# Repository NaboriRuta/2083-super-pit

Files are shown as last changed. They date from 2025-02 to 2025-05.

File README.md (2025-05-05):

# 2083-super-pit
#### Design by Shelton Adams
#### To download these files, download git and run one of these commands in your computer's terminal:

1. For SOLIDWORKS Files: ```git clone https://github.com/NaboriRuta/2083-super-pit/tree/swx```
2. For STEP Files: ```git clone https://github.com/NaboriRuta/2083-super-pit/tree/step```

## Some important things to note:
- Parts modeled can all be found at [The DIY Road Cases Store](https://diyroadcasesstore.com)
  - Some dimensions weren't included, but everything is as accurate as possible
  - I'd suggest looking at [Penn-Elcom](https://penn-elcom.com) for more parts because they have more parts and the DIY Road Cases Store gets basically everything from them
- The plywood our team used is 15/32" thick
- Dimensions are rounded down to the nearest 1/16"
- When it comes to placements of tongue and groove extrusions: All tongue extrusions are on the main bottom compartment and groove extrusions are everywhere else

## Quick File Description
- plywood-cut-lists contains a cut list of how the pieces are cut out initially as well as what the finished pieces will end up looking like
- swx-files contains all of the SOLIDWORKS CAD files used
- step-files contains the main sections of the SOLIDWORKS files, just in .STEP format so it's compatible with all CAD software
- model-pics contains pictures of the Super Pit for people who don't have SOLIDWORKS or any form of CAD on their computer

## For CAD People
- You will notice parts like "Tongue Extrusion Alt 1"
  - These are so the assemblies don't make a bunch of errors when rebuilding
- Some designs were too detail-intensive to do from scratch, so you'll see lots of boxes with the same overall dimensions and the name carved out
- Due to all dimensions being rounded down to the nearest 1/16", there are gaps between:
  - Edges where aluminum extrusions meet
  - the pit pieces themselves when the full assembly is in its closed state
- Each piece does need to be changed individually. Adding global variables to dimensions unfortunately breaks everything
- If you're changing the design to be less than 4' tall/wide, the back wall of the front half no longer needs to be two separate pieces
- Cut Lists can be changed to fit pieces differently, if you're changing the CAD at all
- step-files doesn't contain all of the files used due to the nature of how step files work
  - Separate documents can be made for the individual parts outside of the assembly

#### If you have any questions, feel free to respond to the [Delphi Post](./) (Not Out Yet) or message me via Discord (@naboriruta)

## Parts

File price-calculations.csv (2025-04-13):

Item | Units Needed | Price Per Unit | Total | Additional Comments | Lengths Used (in) | Lengths Per Unit (in) | Lengths Bought (in)
Double Laminated Plywood | 5 | $127.00 | $635.00 | Refer to Cut Lists Here
Single Angle Extrusion | 8 | $12.80 | $102.40 | Dimensions to the right are measured using SWX | 596.5 | 79 | 632
Tongue Extrusion | 2 | $22.70 | $45.40 | Dimensions to the right are measured using SWX | 257.75 | 144 | 288
Groove Extrusion | 3 | $24.00 | $72.00 | Dimensions to the right are measured using SWX | 381.625 | 144 | 432
U-Shape Extrusion | 3 | $12.40 | $37.20 | Dimensions to the right are measured using SWX | 205.75 | 78 | 234
Panel Joiner | 1 | $48.20 | $48.20 | Dimensions to the right are measured using SWX | 71 | 79 | 79
Latches - Recessed | 14 | $11.85 | $165.90
Latches - Surface | 2 | $6.50 | $13.00
Handles | 16 | $6.40 | $102.40 | Refer to Super Pit Pics for placement instruction
Corners | 8 | $2.10 | $16.80 | Refer to Super Pit Pics for placement instruction
Hinge | 1 | $16.60 | $16.60
Rivets - Type 1 | 850 | $0.12 | $102.00
Rivets - Type 2 | 850 | $0.11 | $93.50
Backing Washers | 850 | $0.09 | $76.50
Subtotal for a Single Super Pit Half |  |  | $1,526.90 | Goal: Sub-2K (We did it!!)
Another Super Pit Half | 1 | $1,526.90 | $1,526.90
Wheels/Casters | 6 | $28.60 | $171.60 | Casters from Husky Toolbox will be on one, these will be on the other
Butcher Block | 1 | $189.00 | $189.00 | Needs finish
6' Husky Tool Bench | 1 | $1,298.00 | $1,298.00
Grand Total |  |  | $4,712.40 | Before Tax plus S&H

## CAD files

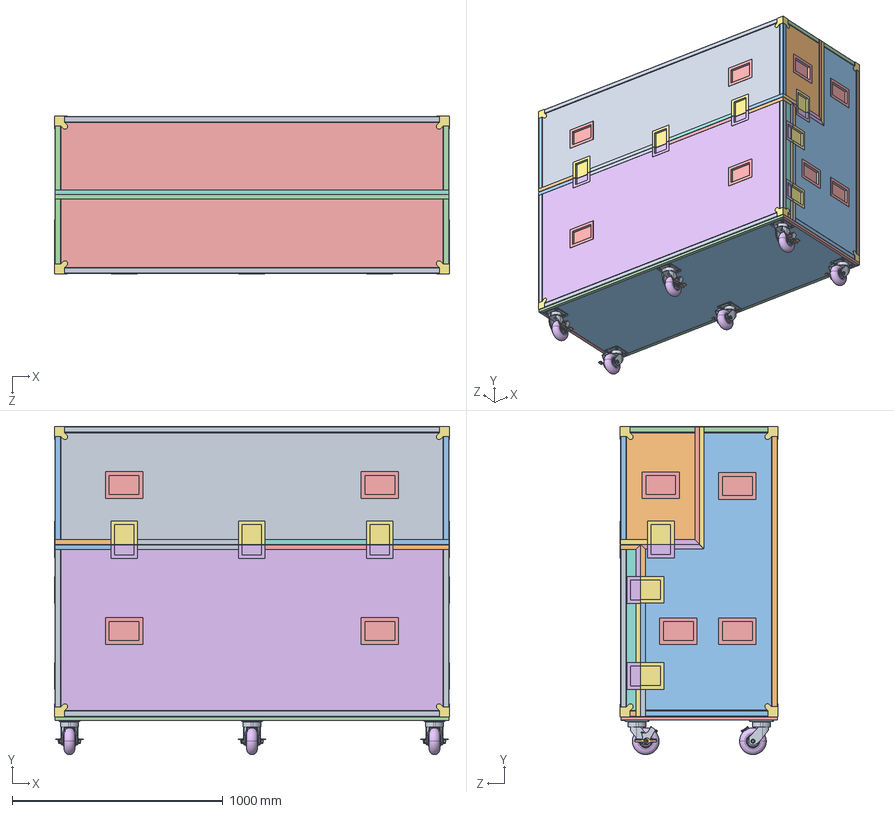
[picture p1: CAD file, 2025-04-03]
step-files/Full Assemblies/Full Super Pit - Closed.STEP
1872.8 x 1556.0 x 748.4 mm
Plywood Panels_Floor
Plywood Panels_Back Wall
Plywood Panels_Side Wall x 2
Plywood Panels_Lower half Top Back
Plywood Panels_Roof x 2
Panel Joiner
Corner Bracket x 8
Tongue Extrusion_Horizontal x 2
Tongue Extrusion_Lower Right Vertical Bottom Half
Tongue Extrusion Alt 1_Lower Left Vertical Bottom Half
Tongue Extrusion Alt 1_Along Z Right Bottom Half
Tongue Extrusion Alt 2_Along Z Left Bottom Half
Tongue Extrusion Alt 3_Upper Right Vertical Bottom Half
Tongue Extrusion_Upper Left Vertical Bottom Half
Single Angle Extrusion (Edges)_Along X x 4
Single Angle Extrusion (Edges)_Along Y x 2
Single Angle Extrusion (Edges)_Along Z x 2
Single Angle Extrusion (Edges)_Along Z Top x 4
Handle Bracket x 16
Recessed Latch Bracket - Hook x 12
Recessed Latch Bracket - Twist x 9
Support Structure
Plywood Panels_Back Wall Top
Plywood Panels_Side Wall Top x 2
Single Angle Extrusion (Edges)_Along Y Top x 2
Groove Extrusion_Horizontal x 4
Groove Extrusion Alt 1_Right Horizontal Top Half
Groove Extrusion_Along Z Right Top Half
Groove Extrusion Alt 1_Along Z Left Top Half
Groove Extrusion_Left Horizontal Top Half
Plywood Panels_Front Cover Main Piece
Plywood Panels_Front Cover Long Sides
Plywood Panels_Front Cover Short Sides x 2
Single Angle Extrusion (Edges)_Along Y Front Cover x 2
Single Angle Extrusion (Edges)_Along Z Front Cover x 2
Groove Extrusion Alt 1_Along Z Right Front Cover
Groove Extrusion_Right Vertical Front Cover
Groove Extrusion Alt 1_Left Vertical Front Cover
Groove Extrusion_Along Z Left Front Cover
Plywood Panels_Cart Thing
U-shape Extrusion (Non-Corner Edges)_Horizontal Front Cover x 2
U-shape Extrusion (Non-Corner Edges)_Along Z Cart Thing x 2
2793N22_High-Capacity Easy-Turn Caster with Polyurethane Wheel_2793N22 x 6

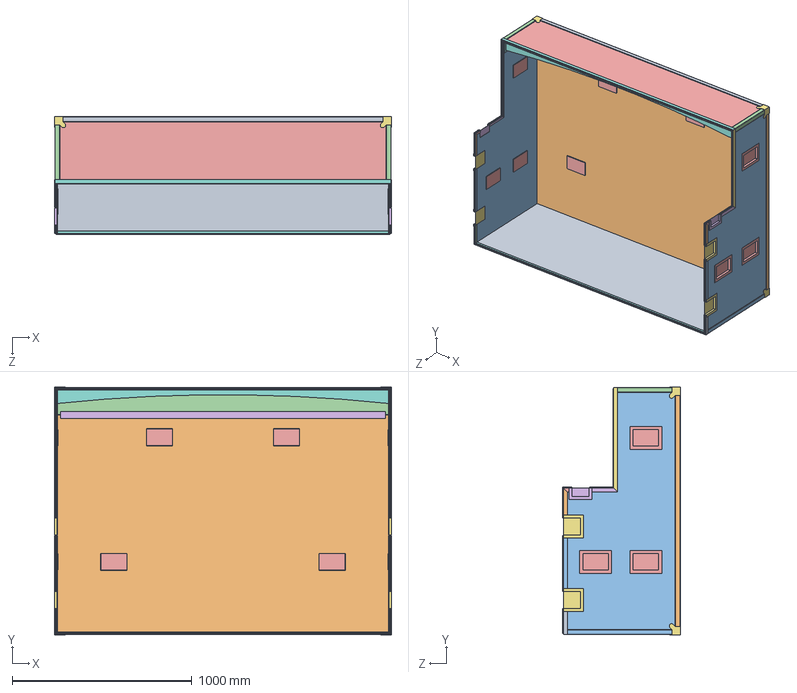
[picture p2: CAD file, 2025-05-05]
step-files/Microassemblies/Super Pit Bottom Half.STEP
1872.8 x 1376.6 x 655.0 mm
Plywood Panels_Floor
Plywood Panels_Back Wall
Plywood Panels_Side Wall x 2
Plywood Panels_Lower half Top Back
Plywood Panels_Roof
Panel Joiner
Corner Bracket x 4
Tongue Extrusion_Horizontal x 2
Tongue Extrusion_Lower Right Vertical Bottom Half
Tongue Extrusion Alt 1_Lower Left Vertical Bottom Half
Tongue Extrusion Alt 1_Along Z Right Bottom Half
Tongue Extrusion Alt 2_Along Z Left Bottom Half
Tongue Extrusion Alt 3_Upper Right Vertical Bottom Half
Tongue Extrusion_Upper Left Vertical Bottom Half
Single Angle Extrusion (Edges)_Along X x 2
Single Angle Extrusion (Edges)_Along Y x 2
Single Angle Extrusion (Edges)_Along Z x 2
Single Angle Extrusion (Edges)_Along Z Top x 2
Handle Bracket x 10
Recessed Latch Bracket - Hook x 2
Recessed Latch Bracket - Twist x 4
Support Structure

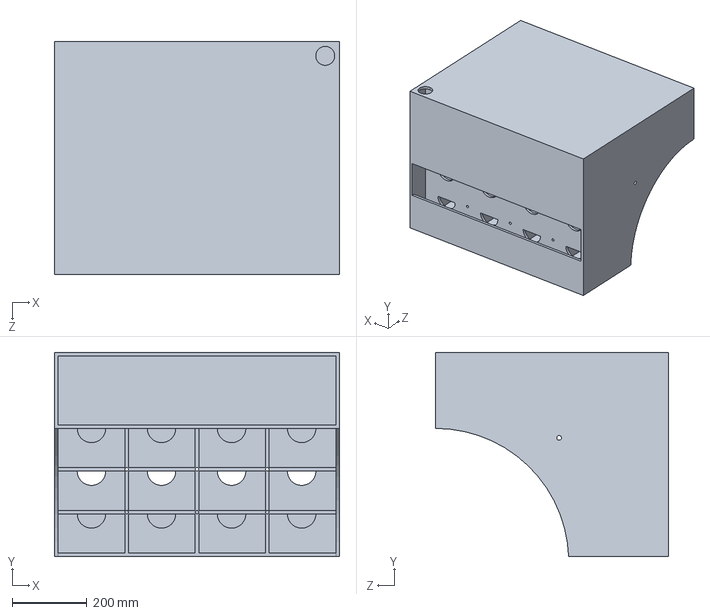
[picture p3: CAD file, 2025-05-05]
step-files/Parts/Battery Holder.STEP
762.0 x 546.1 x 622.3 mm

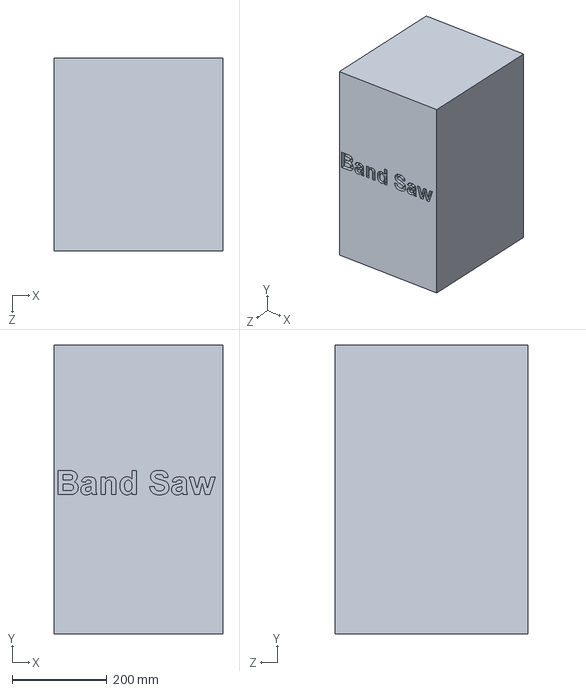
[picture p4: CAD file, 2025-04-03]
step-files/Parts/Stand-Ins/Band Saw Stand-In.STEP
355.6 x 609.6 x 406.4 mm

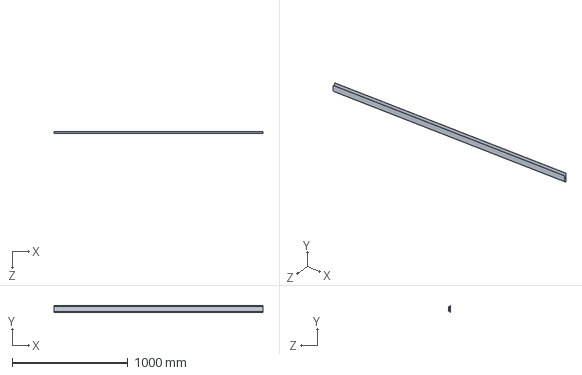
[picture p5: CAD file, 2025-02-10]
swx-files/Parts/Edges and Corners/Panel Joiner.SLDPRT
1803.4 x 63.5 x 15.7 mm

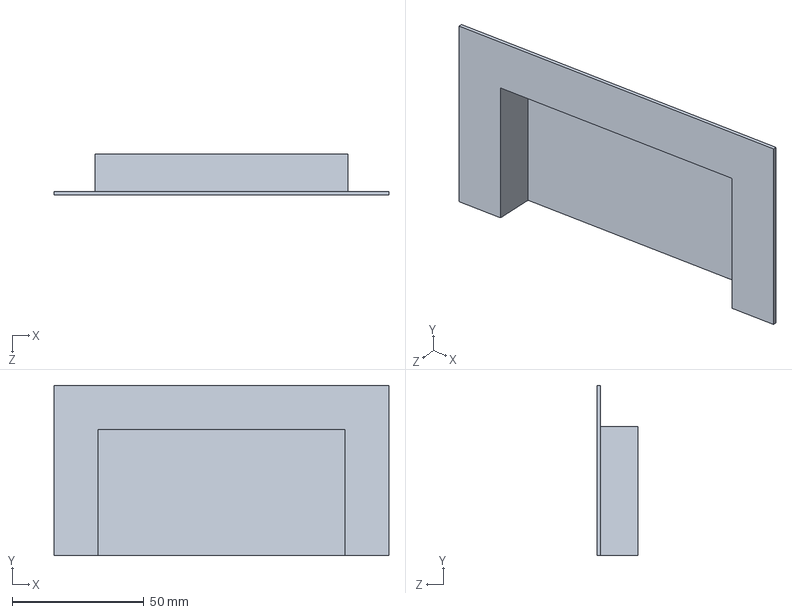
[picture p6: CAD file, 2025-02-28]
swx-files/Parts/Handles and Latches/Recessed Latch Bracket - Hook.SLDPRT
127.0 x 64.5 x 15.5 mm

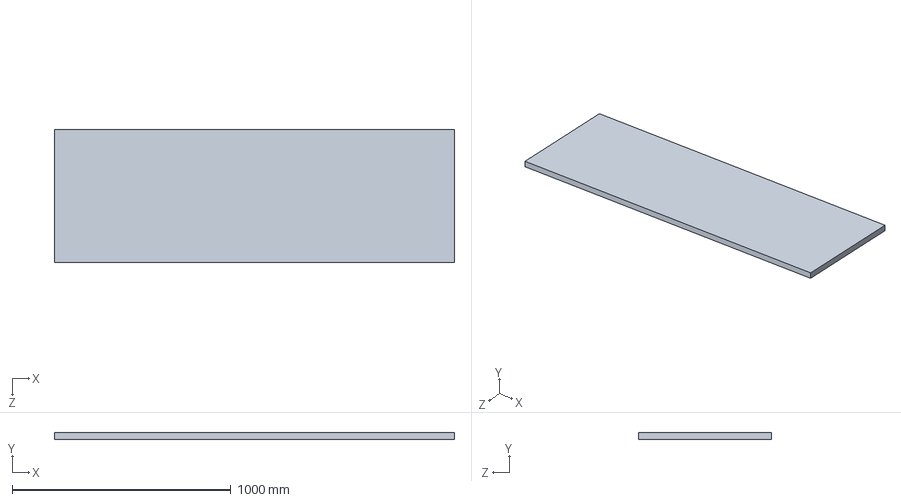
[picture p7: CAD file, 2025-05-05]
swx-files/Parts/Stand-Ins/Butcher Block Stand-In.SLDPRT
1828.8 x 31.8 x 609.6 mm

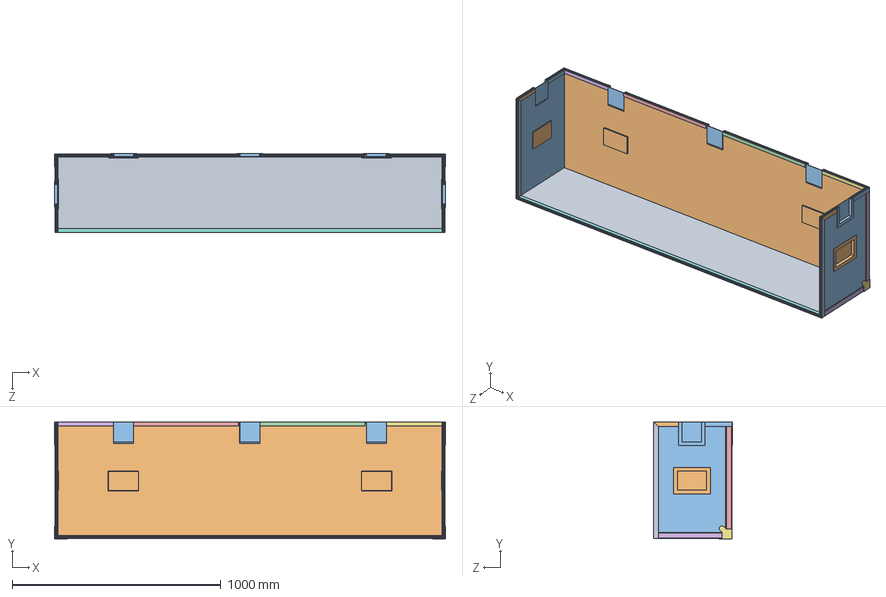
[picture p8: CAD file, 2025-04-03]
step-files/Microassemblies/Super Pit Top Half.STEP
1872.8 x 559.0 x 376.0 mm
Plywood Panels_Roof
Plywood Panels_Back Wall Top
Plywood Panels_Side Wall Top x 2
Single Angle Extrusion (Edges)_Along X
Single Angle Extrusion (Edges)_Along Y Top x 2
Single Angle Extrusion (Edges)_Along Z Top x 2
Corner Bracket x 2
Groove Extrusion_Horizontal x 2
Groove Extrusion Alt 1_Right Horizontal Top Half
Groove Extrusion_Along Z Right Top Half
Groove Extrusion Alt 1_Along Z Left Top Half
Groove Extrusion_Left Horizontal Top Half
Handle Bracket x 4
Recessed Latch Bracket - Twist x 5

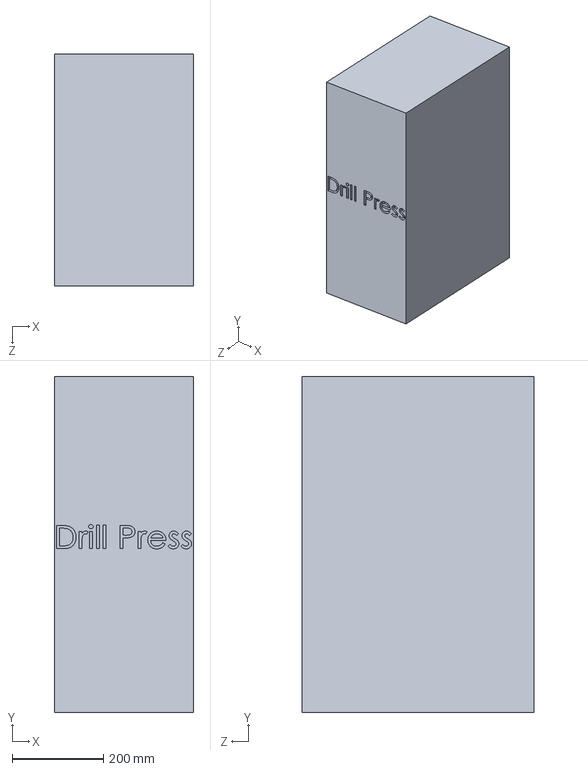
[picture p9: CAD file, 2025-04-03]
step-files/Parts/Stand-Ins/Drill Press Stand-In.STEP
304.8 x 736.6 x 508.0 mm

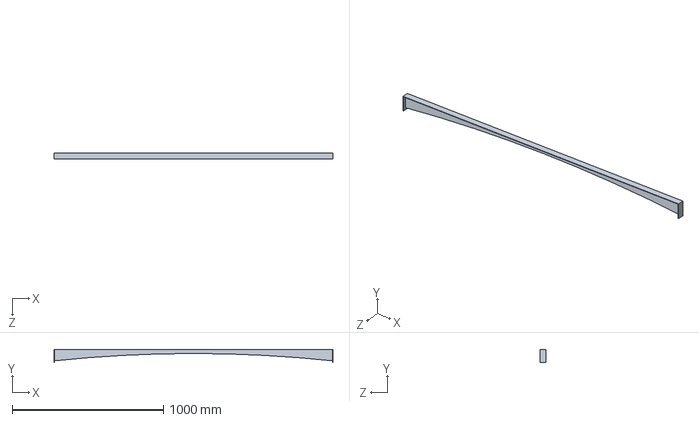
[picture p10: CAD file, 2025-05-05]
step-files/Parts/Support Structure.STEP
1843.1 x 88.9 x 38.1 mm

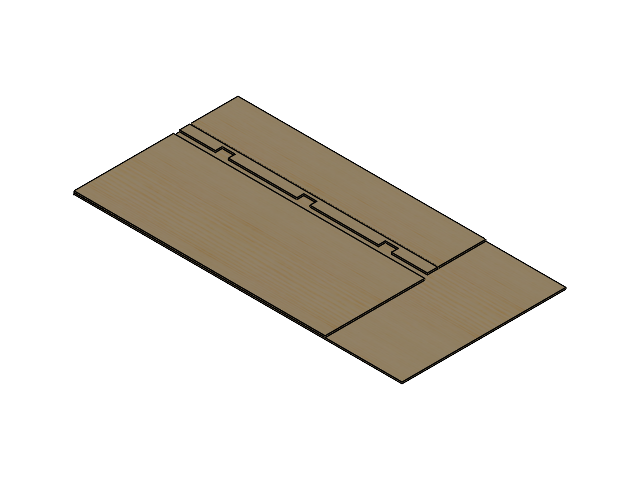
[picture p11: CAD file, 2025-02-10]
swx-files/Cut List/Assembly for Cut List.SLDASM
Plywood Panels x 4

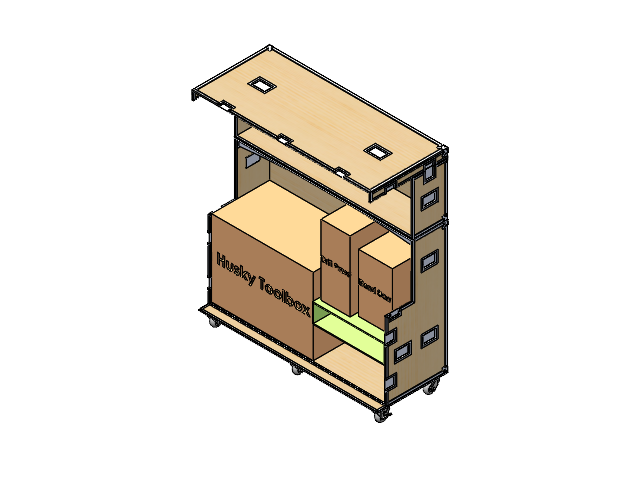
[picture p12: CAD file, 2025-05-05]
swx-files/Full Assemblies/Full Super Pit.SLDASM
Plywood Panels x 15
Panel Joiner
Corner Bracket x 8
Tongue Extrusion x 4
Tongue Extrusion Alt 1 x 2
Tongue Extrusion Alt 2
Tongue Extrusion Alt 3
Single Angle Extrusion (Edges) x 18
Handle Bracket x 16
Recessed Latch Bracket - Hook x 12
Recessed Latch Bracket - Twist x 9
Support Structure
Groove Extrusion x 8
Groove Extrusion Alt 1 x 4
U-shape Extrusion (Non-Corner Edges) x 4
2793N22_High-Capacity Easy-Turn Caster with Polyurethane Wheel x 6
Husky Toolbox Stand-in
Drill Press + Band Saw Stand-In x 2
Battery Holder

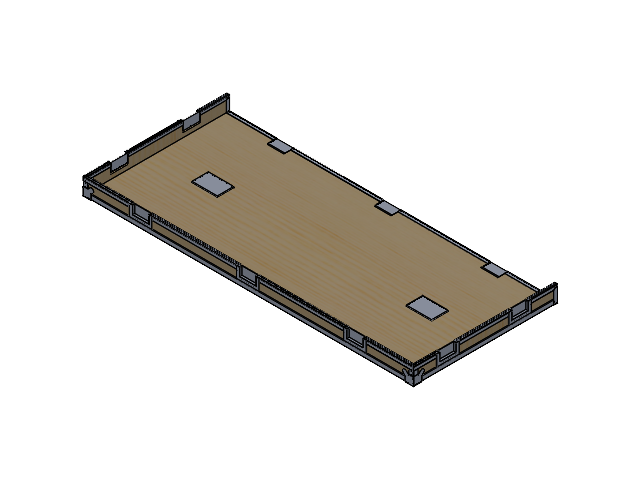
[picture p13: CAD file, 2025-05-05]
swx-files/Microassemblies/Super Pit Front Cover.SLDASM
Plywood Panels x 4
Single Angle Extrusion (Edges) x 5
Corner Bracket x 2
Groove Extrusion x 4
Groove Extrusion Alt 1 x 2
Handle Bracket x 2
Recessed Latch Bracket - Hook x 10

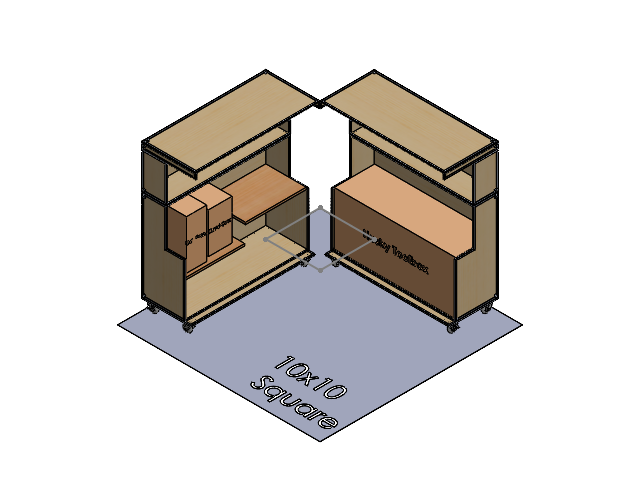
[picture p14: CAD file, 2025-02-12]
swx-files/Full Assemblies/Pit Setup, maybe.SLDASM
10x10 square
Plywood Panels x 31
Panel Joiner x 2
Corner Bracket x 16
Tongue Extrusion x 8
Tongue Extrusion Alt 1 x 4
Tongue Extrusion Alt 2 x 2
Tongue Extrusion Alt 3 x 2
Single Angle Extrusion (Edges) x 36
Handle Bracket x 32
Recessed Latch Bracket - Hook x 24
Recessed Latch Bracket - Twist x 18
Groove Extrusion x 16
Groove Extrusion Alt 1 x 8
U-shape Extrusion (Non-Corner Edges) x 8
2793N22_High-Capacity Easy-Turn Caster with Polyurethane Wheel x 8
Butcher Block Stand-In x 2
Drill Press + Band Saw Stand-In x 2
Battery Holder
Husky Toolbox Stand-in

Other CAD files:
swx-files/Microassemblies/Super Pit Top Half.SLDASM
swx-files/Microassemblies/Super Pit Bottom Half.SLDASM
swx-files/Microassemblies/Cart Thing.SLDASM
swx-files/Parts/Battery Holder.SLDPRT
step-files/Microassemblies/Cart Thing.STEP
step-files/Microassemblies/Super Pit Front Cover.STEP
step-files/Parts/Plywood Divider.STEP
step-files/Parts/Stand-Ins/Butcher Block Stand-In.STEP
swx-files/Cut List/Cut List.SLDDRW
swx-files/Cut List/Final Pieces.SLDDRW
swx-files/Parts/10x10 square.SLDPRT
swx-files/Parts/2793N22_High-Capacity Easy-Turn Caster with Polyurethane Wheel.SLDPRT
swx-files/Parts/Crank Handle Extension Thing Because Pit Crew Lost The Handle.SLDPRT
swx-files/Parts/Edges and Corners/Corner Bracket.SLDPRT
swx-files/Parts/Edges and Corners/Groove Extrusion Alt 1.SLDPRT
swx-files/Parts/Edges and Corners/Groove Extrusion.SLDPRT
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

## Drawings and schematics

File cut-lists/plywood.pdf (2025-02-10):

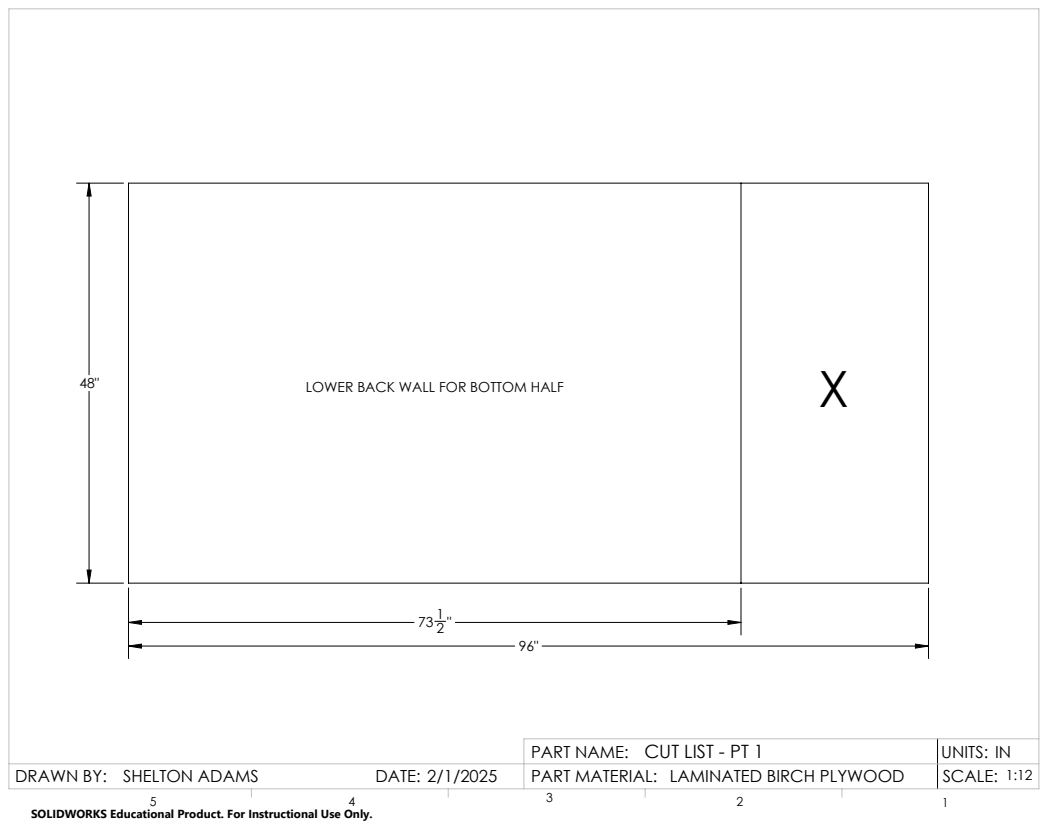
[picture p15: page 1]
LOWER BACK WALL FOR BOTTOM HALF

CUT LIST - PT 1 PART NAME: | UNITS: IN

DRAWN BY: SHELTON ADAMS DATE: 2/1/2025 | PART MATERIAL: LAMINATED BIRCH PLYWOOD | SCALE:

SOLIDWORKS Educational Product. For Instructional Use Only.

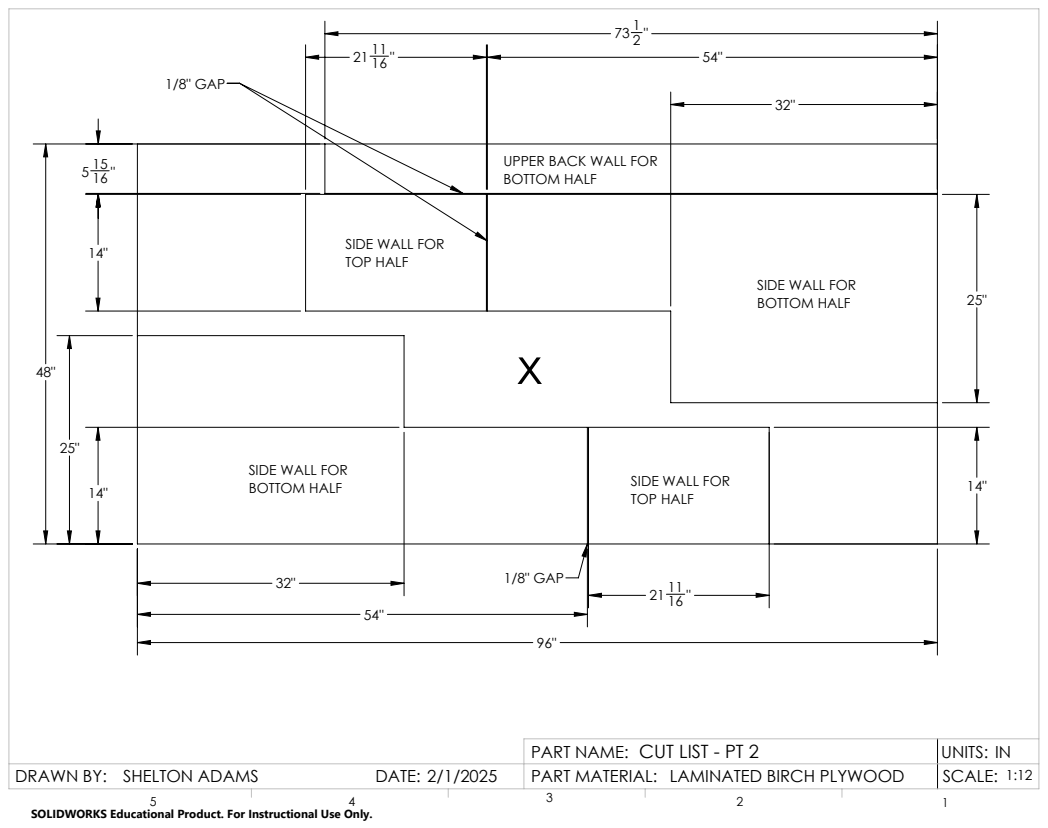
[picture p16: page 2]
1/8" GAP; PART NAME:

UPPER BACK WALL FOR BOTTOM HALF

SIDE WALL FOR TOP HALF

SIDE WALL FOR
BOTTOM HALF

TOP HALF

CUT LIST - PT 2

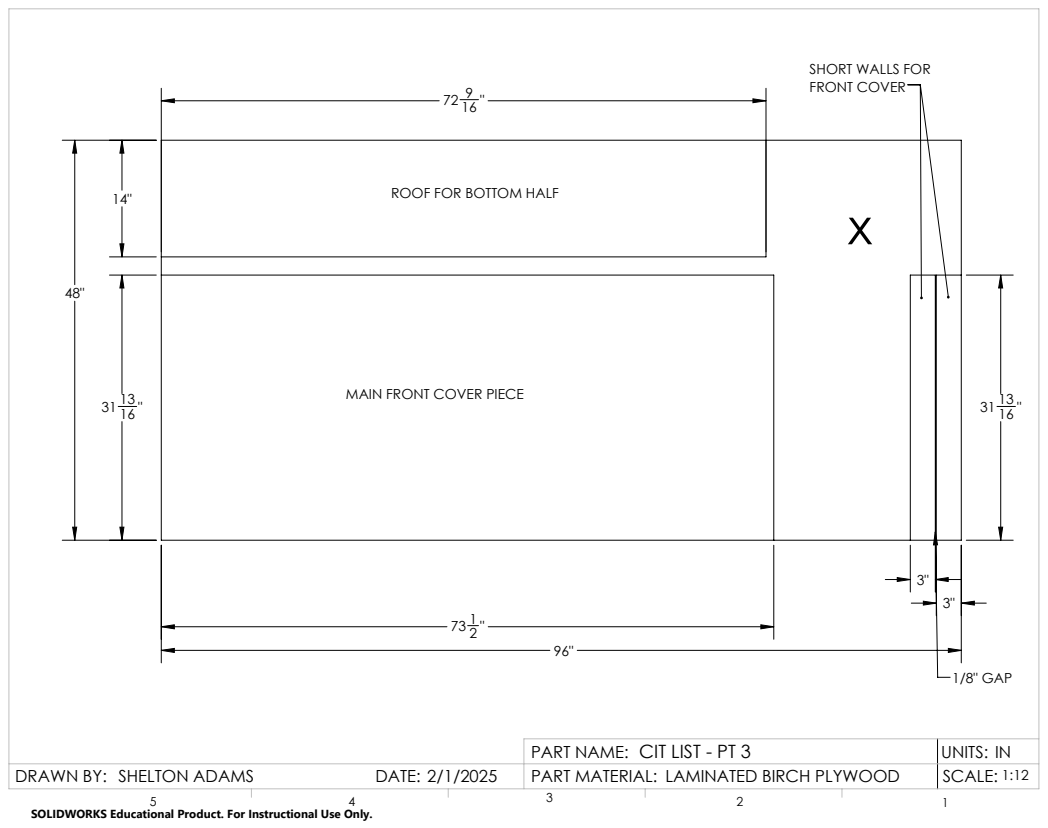
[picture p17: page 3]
1/8" GAP; PART NAME:

SHORT WALLS FOR
FRONT COVER

ROOF FOR BOTTOM HALF

MAIN FRONT COVER PIECE

CIT LIST - PT 3

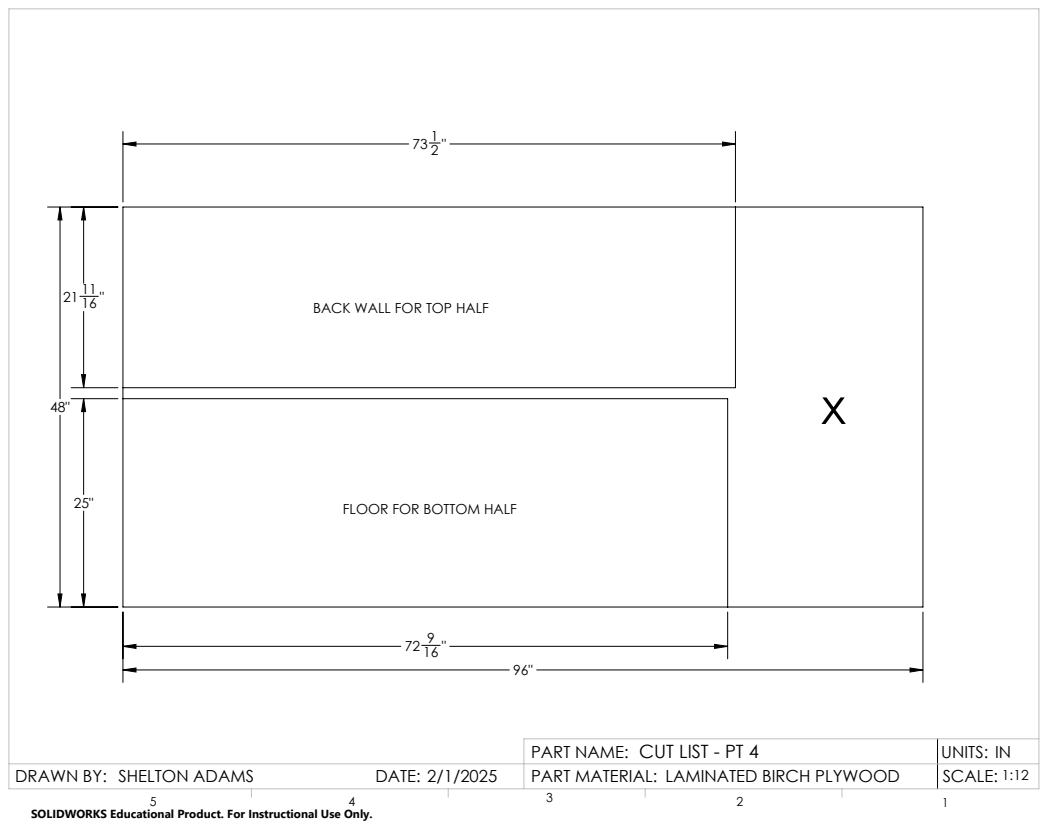
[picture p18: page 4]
PART NAME:

BACK WALL FOR TOP HALF

FLOOR FOR BOTTOM HALF

CUT LIST - PT 4

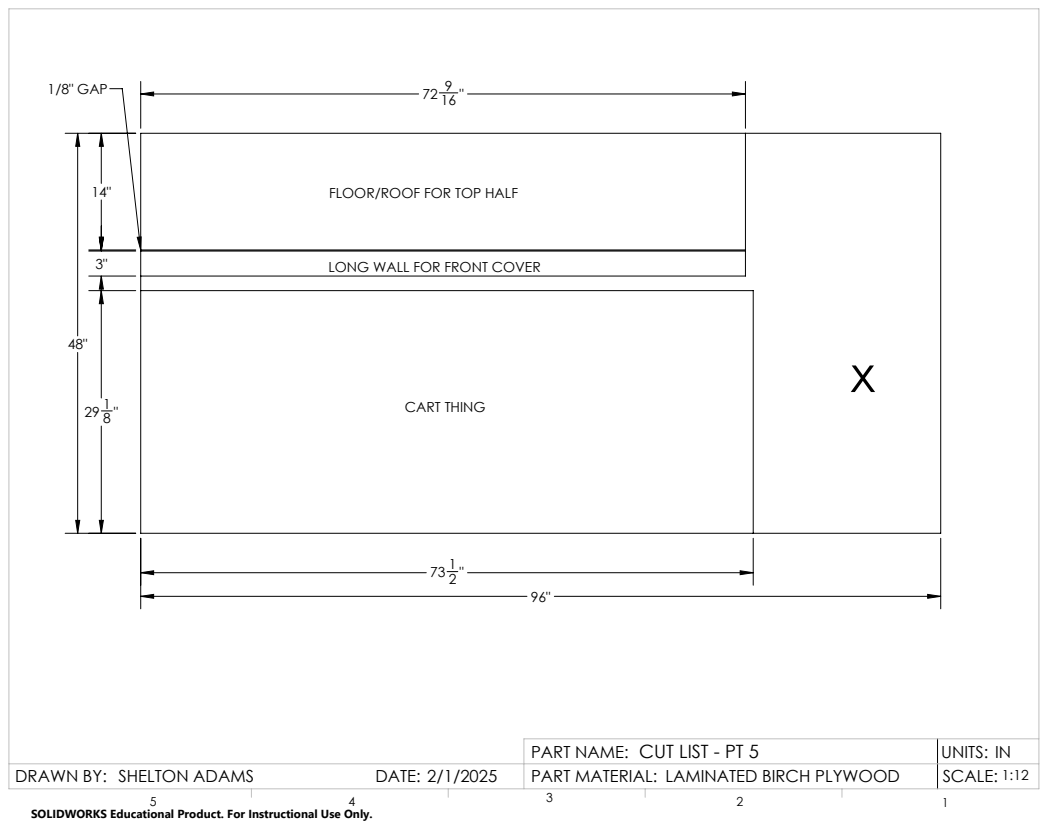
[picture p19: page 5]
CART THING; 1/8" GAP; PART NAME:

FLOOR/ROOF FOR TOP HALF

LONG WALL FOR FRONT COVER

CUT LIST - PT 5

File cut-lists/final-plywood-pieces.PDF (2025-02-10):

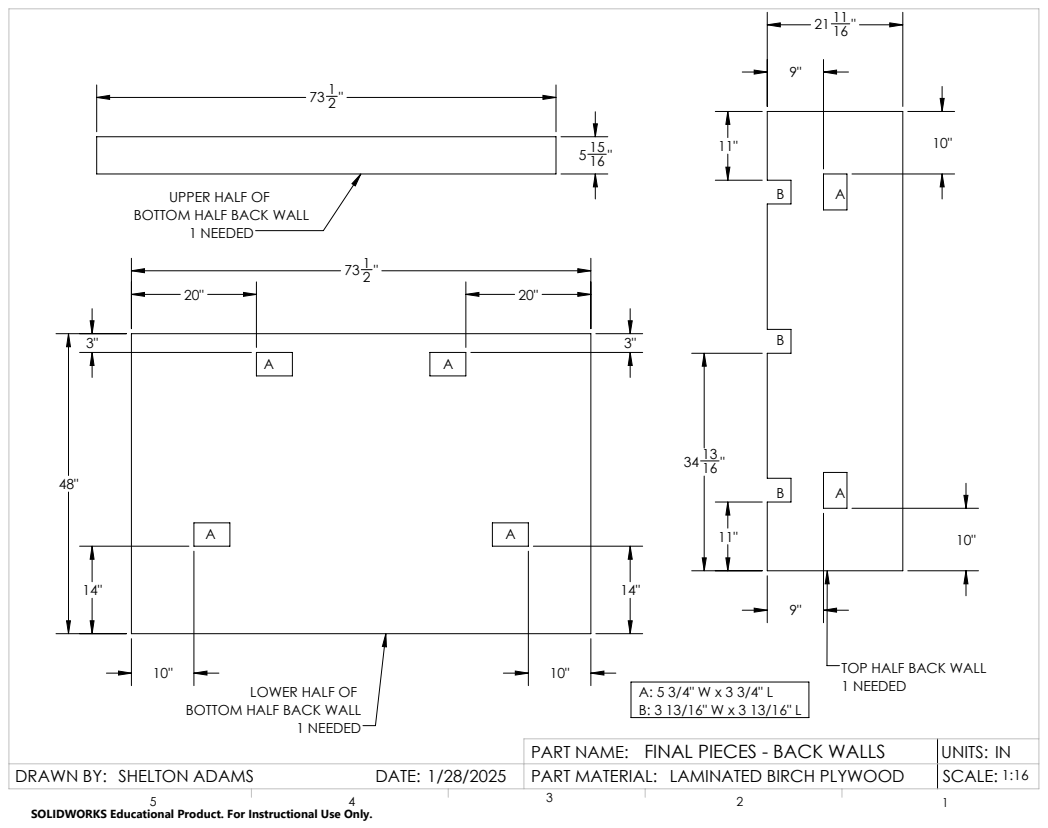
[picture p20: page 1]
1 NEEDED

UPPER HALF OF
BOTTOM HALF BACK WALL
1 NEEDED

TOP HALF BACK WALL

LOWER HALF OF

FINAL PIECES - BACK WALLS PART NAME: | UNITS: IN

DRAWN BY: SHELTON ADAMS DATE: 1/28/2025 | PART MATERIAL: LAMINATED BIRCH PLYWOOD | SCALE:

SOLIDWORKS Educational Product. For Instructional Use Only.

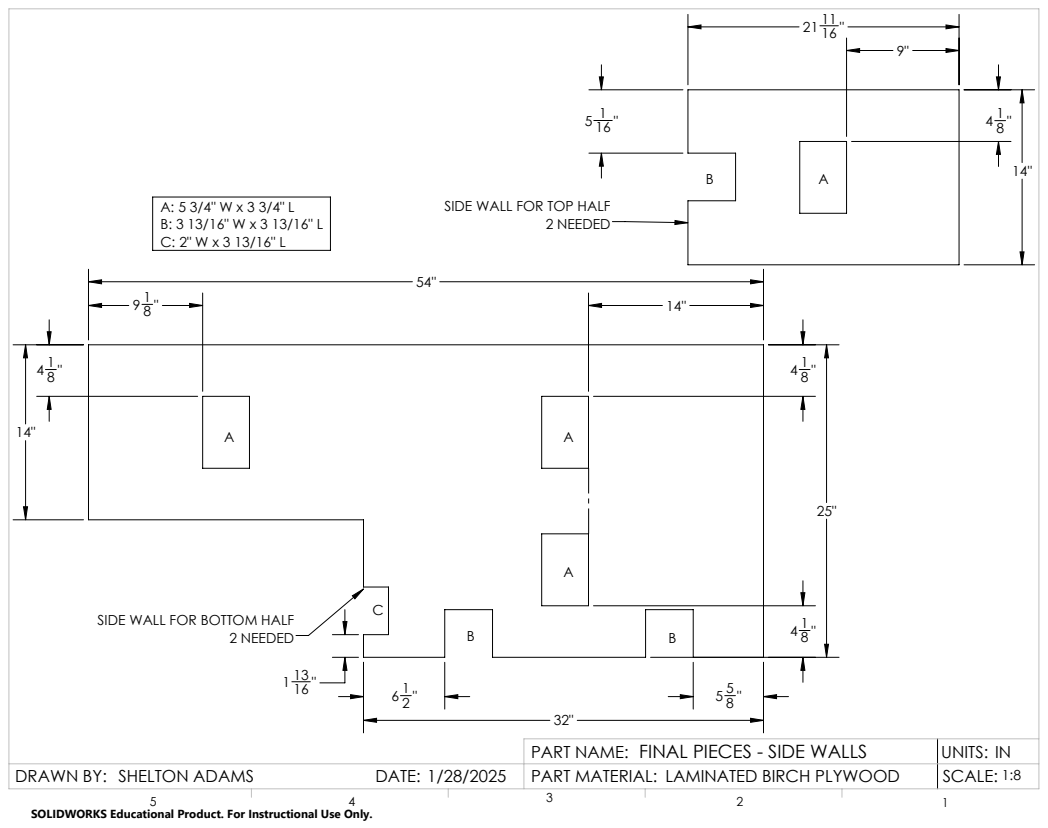
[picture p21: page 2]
2 NEEDED; PART NAME:

SIDE WALL FOR TOP HALF

SIDE WALL FOR BOTTOM HALF

FINAL PIECES - SIDE WALLS

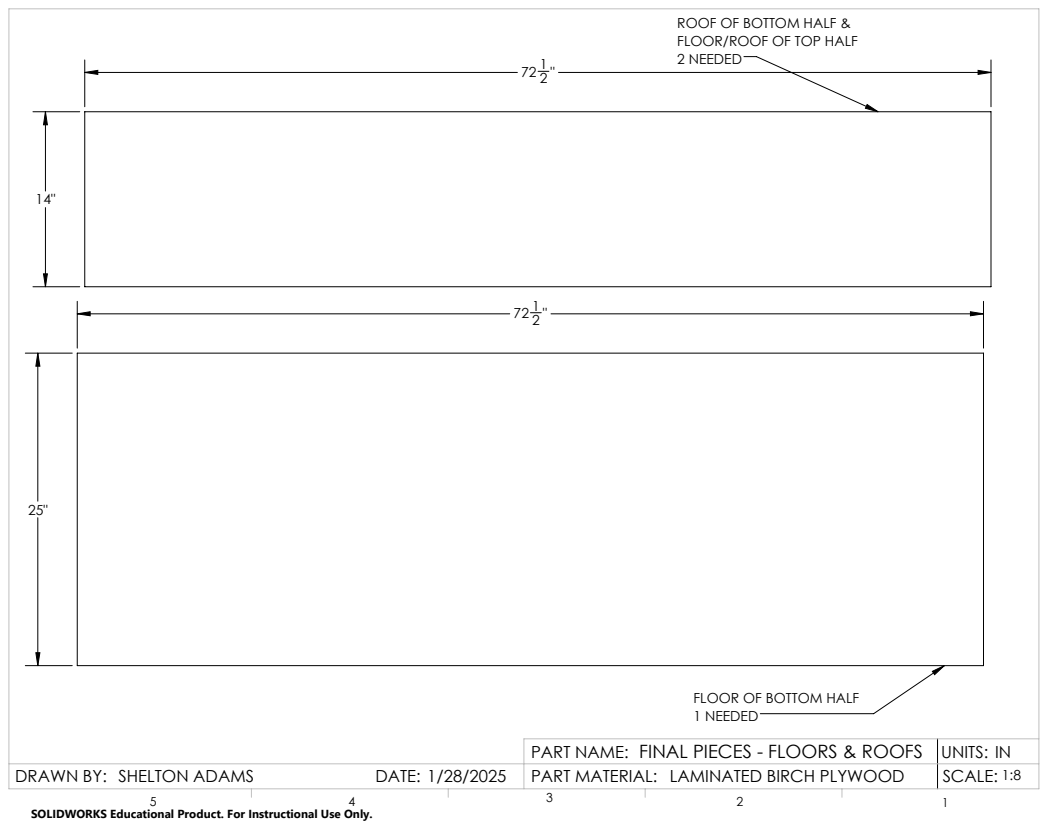
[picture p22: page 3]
PART NAME:

ROOF OF BOTTOM HALF &
FLOOR/ROOF OF TOP HALF
2 NEEDED

FLOOR OF BOTTOM HALF
1 NEEDED
FINAL PIECES - FLOORS & ROOFS

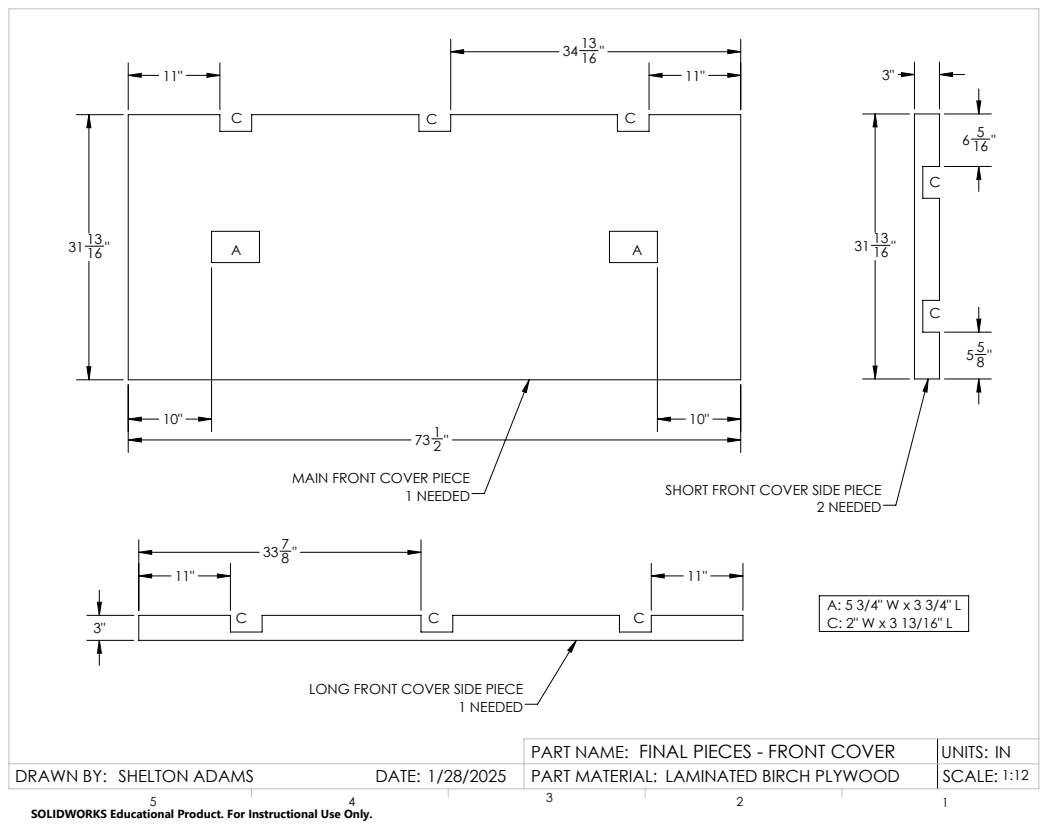
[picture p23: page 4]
1 NEEDED; 2 NEEDED; PART NAME:

MAIN FRONT COVER PIECE

SHORT FRONT COVER SIDE PIECE

LONG FRONT COVER SIDE PIECE

FINAL PIECES - FRONT COVER

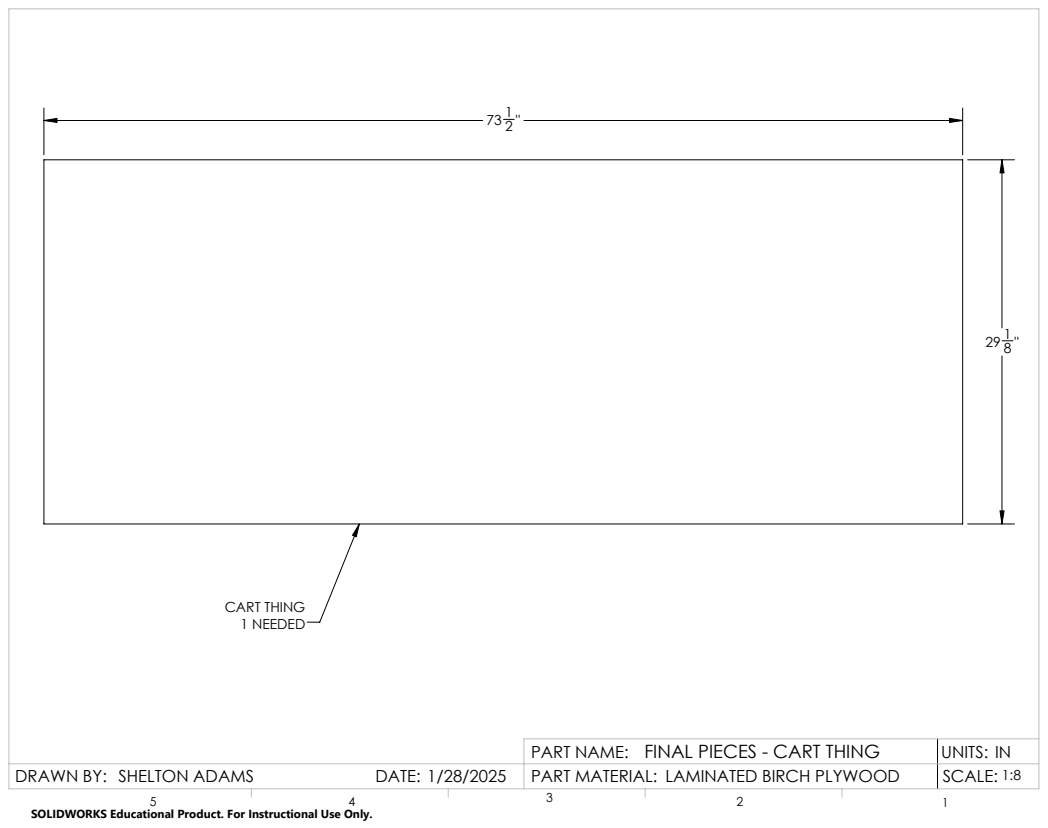
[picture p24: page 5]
CART THING 1 NEEDED; PART NAME:

FINAL PIECES - CART THING

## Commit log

2025-02-10 first repo upload
    [10x10 square.SLDPRT, 2793N22_High-Capacity Easy-Turn Caster with Polyurethane Wheel.SLDPRT, Assembly for Cut List.SLDASM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]
2025-02-10 cad files first commit
    [10x10 square.SLDPRT, 2793N22_High-Capacity Easy-Turn Caster with Polyurethane Wheel.SLDPRT, Assembly for Cut List.SLDASM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]
2025-02-10 add cut lists
2025-02-12 add price calcs
    [Price Calculations - Sheet1.csv]
2025-02-12 updated battery holder
    [Battery Holder.SLDPRT, Full Super Pit.SLDASM, Pit Setup, maybe.SLDASM]
2025-02-19 update cad files
    [Battery Holder.SLDPRT, Cart Thing.SLDASM, Full Super Pit.SLDASM]
2025-02-28 Update cad
    [Battery Holder.SLDPRT, Full Super Pit.SLDASM, Handle Bracket.SLDPRT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]
2025-04-03 Add .STEP Files
    [Band Saw Stand-In.STEP, Butcher Block Stand-In.STEP, Cart Thing.STEP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]
2025-04-03 Add SWX Files
    [10x10 square.SLDPRT, 2793N22_High-Capacity Easy-Turn Caster with Polyurethane Wheel.SLDPRT, Assembly for Cut List.SLDASM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]
2025-04-16 Update SWX Configs
    [Battery Holder.SLDPRT, Butcher Block Stand-In.SLDPRT, Crank Handle Extension Thing Because Pit Crew Lost The Handle.SLDPRT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]
2025-05-05 Update SWX Files
    [Battery Holder.SLDPRT, Butcher Block Stand-In.SLDPRT, Cart Thing.SLDASM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]
2025-05-05 Update STEP Files
    [Battery Holder.STEP, Super Pit Bottom Half.STEP, Support Structure.STEP]
